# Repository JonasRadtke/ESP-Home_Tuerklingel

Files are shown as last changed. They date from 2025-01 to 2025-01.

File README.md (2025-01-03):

# ESP-Home Tuerklingel

Dies Projekt bringt meine alte Türklingel bzw den Türöffner in Home-Assistent über ESP-Home.

- ESP8266 - muss vorher geflasht werden, bevor es auf das Board gelötet wird. Danach kann OTA geupdatet werden.
- 2x Optokoppler - für Klingelknopf unten und Klingelknopf oben
- 1x Mosfet-Relais - zum bedienen des Türöffners

Meine Türklingel wird per 8V Trafo aus dem Keller versorgt. Auch die Signale sind demnach 8V.

ESP-Home Home-Assistant Config in der YAML Datei.

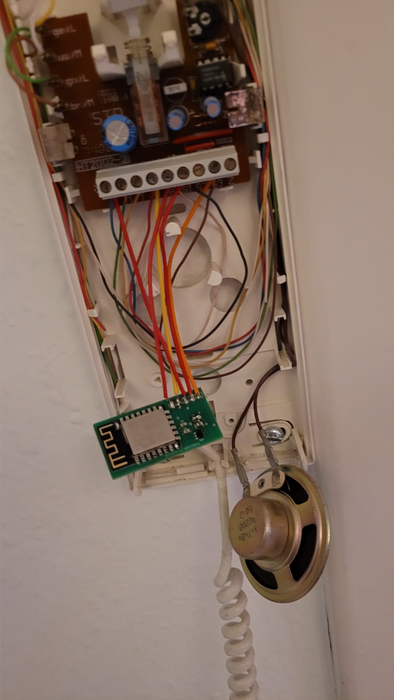
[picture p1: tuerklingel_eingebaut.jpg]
x


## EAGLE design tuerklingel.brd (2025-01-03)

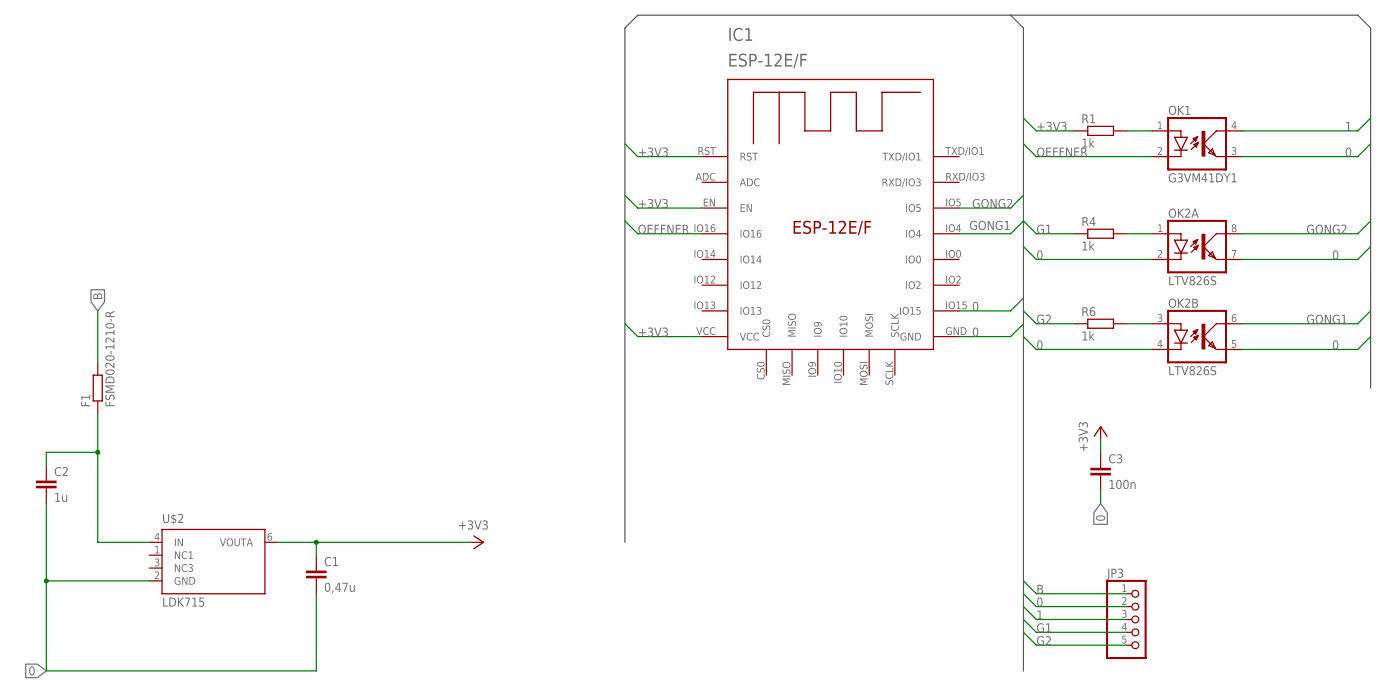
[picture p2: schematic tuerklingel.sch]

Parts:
C1: 0,47u; C0805
C2: 1u; C0805
C3: 100n; C0805
F1: FSMD020-1210-R; R1210
IC1: ESP-12E/F; ESP-12E
JP3: PINHD-1X5; 1X05
OK1: G3VM41DY1; DIL4-SMD
OK2: LTV826S; DIL8-SMD
R1, R4, R6: 1k; R0805
U$2: LDK715; SOT23-6

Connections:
0: C1.2, C2.2, C3.2, IC1.GND, IC1.IO15, JP3.2, OK1.3 (EMIT), OK2.2 (C), OK2.4 (C), OK2.5 (EMIT), OK2.7 (EMIT), U$2.2 (GND)
1: JP3.3, OK1.4 (COL)
+3V3: C1.1, C3.1, IC1.EN, IC1.RST, IC1.VCC, R1.1, U$2.6 (VOUTA)
B: F1.2, JP3.1
G1: JP3.4, R4.1
G2: JP3.5, R6.1
GONG1: IC1.IO4, OK2.6 (COL)
GONG2: IC1.IO5, OK2.8 (COL)
unnamed: C2.1, F1.1, U$2.4 (IN)
unnamed: OK1.1 (A), R1.2
unnamed: OK2.1 (A), R4.2
unnamed: OK2.3 (A), R6.2
OEFFNER: IC1.IO16, OK1.2 (C)

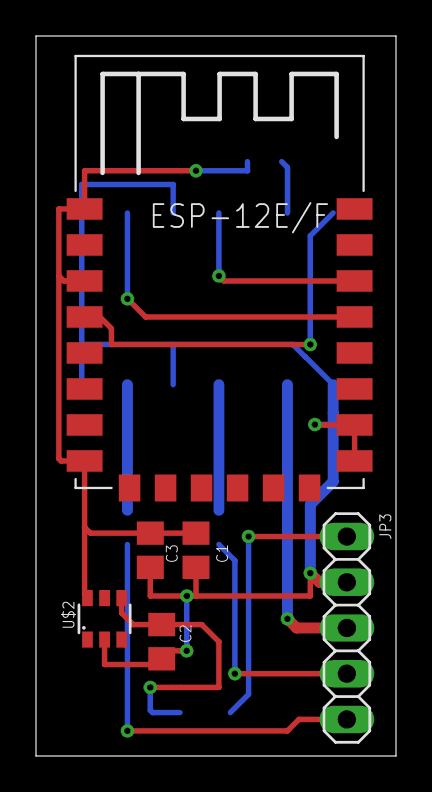
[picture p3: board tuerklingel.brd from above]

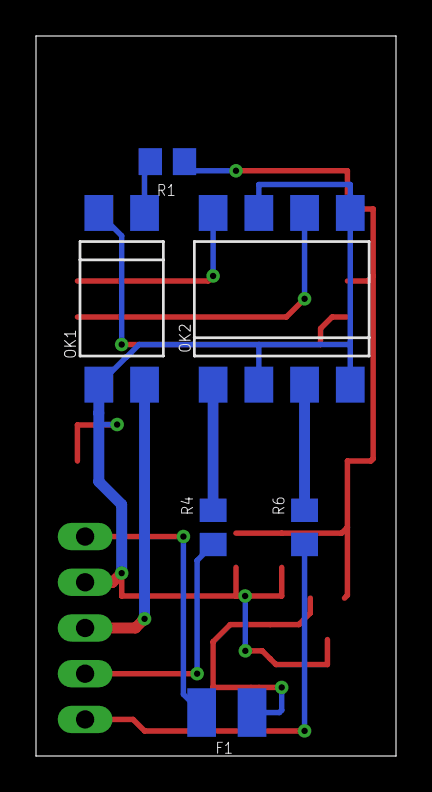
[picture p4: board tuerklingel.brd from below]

Board: 2 copper layers, 20.0 x 40.0 mm, 12 parts (6 on the bottom side), 13 nets.
